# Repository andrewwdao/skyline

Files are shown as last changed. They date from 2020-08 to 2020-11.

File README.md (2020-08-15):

| Supported Targets | ESP32 |
| --- | ----- |

# SOURCE CODE FOR THE SKYLINE SYSTEM

This folder is the source code for the skyline system which will use MCPWM module to control brushed dc motor, with local webserver control, wifi-manager integrated and 04 button for direct interaction.
 
This code is tested with VNH3ASP30 motor driver.

(c) 2020 Minh-An Dao, MIS-CTU, Can Tho

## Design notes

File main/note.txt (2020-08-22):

https://docs.espressif.com/projects/esp-idf/en/release-v4.2/esp32/api-guides/build-system.html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

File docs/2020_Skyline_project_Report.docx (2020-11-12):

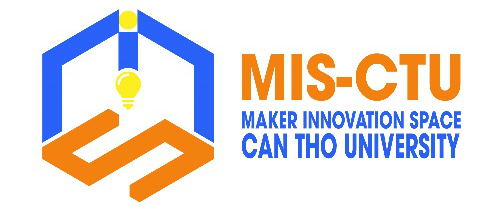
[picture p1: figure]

Người báo cáo:

- Nguyễn Khánh Trân Thiết kế cơ khí

- Nguyễn Minh Luân Thiết kế cơ khí

- Trần Thị Như Phụng Thiết kế mạch điện tử

- Đào Minh An Lập trình nhúng

Tổng kinh phí dự án:

Thời gian thực hiện:

BÁO CÁO DỰ ÁN

GIẾNG TRỜI ĐIỆN TỬ

08/2020

PHÊ DUYỆT DỰ ÁN

Tên dự án: Giếng trời điện tử

Thời gian thực hiện:

Tổng kinh phí:

Chủ đầu tư dự án:

Nơi áp dụng sản phẩm dự án:

Ngày dự án được phê duyệt thông qua và cho phép sử dụng:

Thành viên thực hiện dự án:

Họ và tên | Trách nhiệm | Ký tên
Nguyễn Khánh Trân | Thiết kế cơ khí
Nguyễn Minh Luân | Thiết kế cơ khí
Trần Thị Như Phụng | Thiết kế mạch điện tử
Đào Minh An | Lập trình nhúng
Nguyễn Hoàng Dũng | Chịu trách nhiệm dự án, kiểm duyệt và thông qua dự án

MỤC LỤC

MỤC LỤC HÌNH

# PHẦN 1: THUYẾT MINH DỰ ÁN

## 1.1 MỤC TIÊU DỰ ÁN

Xây dựng hệ thống điều khiển cửa sổ giếng trời thông qua webapp hoặc remote.

## 1.2 KẾT QUẢ MONG ĐỢI CỦA DỰ ÁN

Giếng trời có thể được điều khiển đóng/mở thông qua webapp hoặc remote từ xa.

## 1.3 KẾ HOẠCH THỰC HIỆN

01/09/2020 – 05/09/2020: Thiết kế cơ khí.

06/09/2020 – 07/09/2020: Gia công cơ khí.

01/09/2020 – 07/09/2020: Vẽ mạch điện, lập trình nhúng.

08/09/2020 – 10/09/2020: Thử nghiệm và tiến hành lắp đặt.

## 1.4 DỰ TOÁN KINH PHÍ

# PHẦN 2: THỰC HIỆN DỰ ÁN

## 2.1 THIẾT KẾ PHẦN CỨNG

### 2.1.1 THIẾT KẾ CƠ KHÍ

#### 2.1.1.1 Bản vẽ và mô tả bản vẽ lắp có kích thước

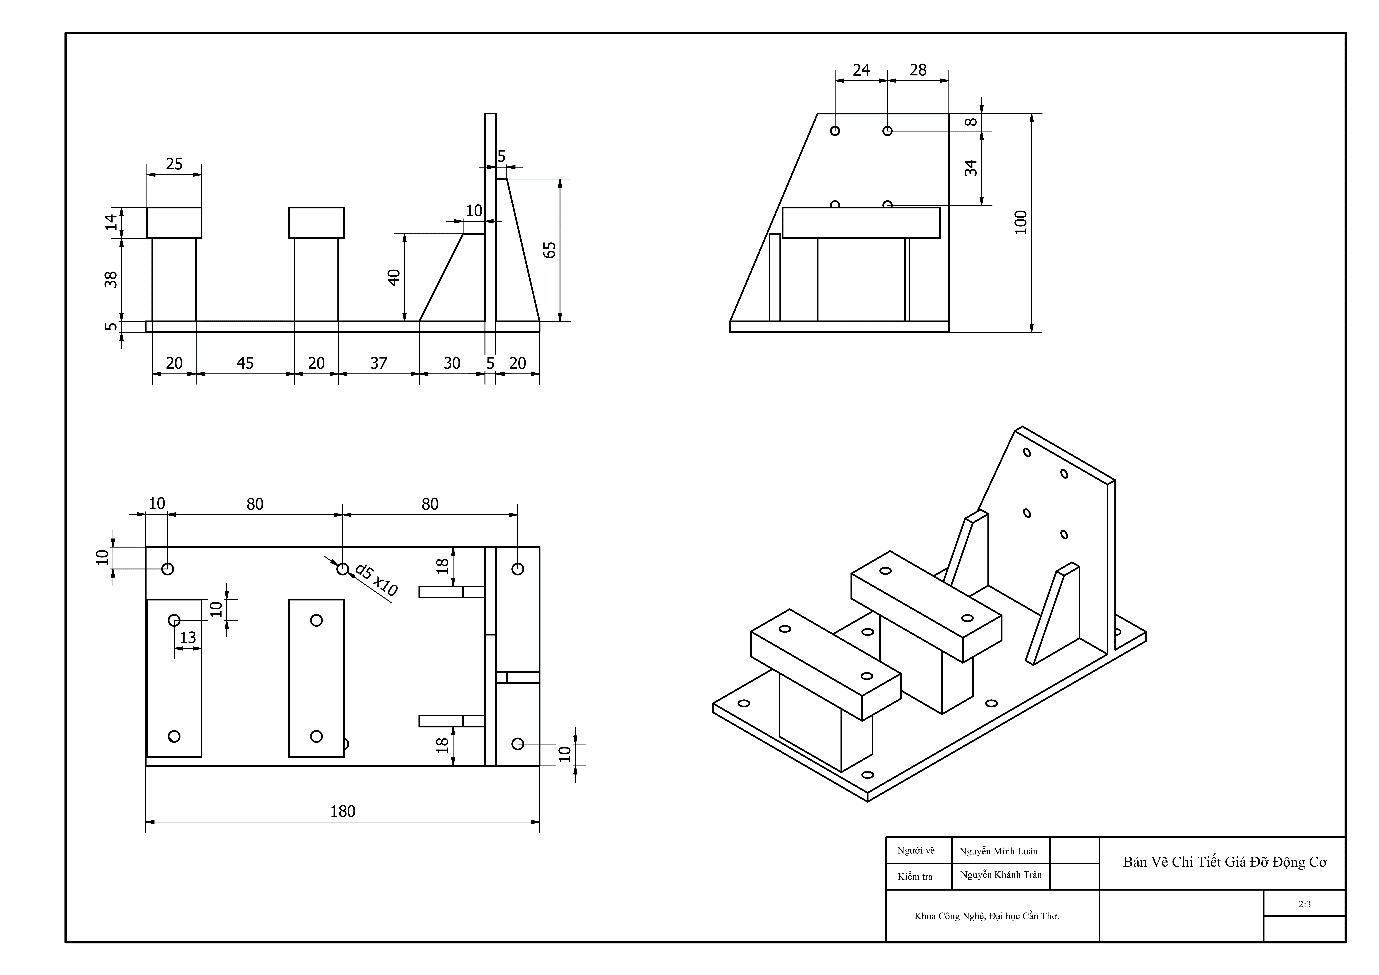
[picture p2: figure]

Hình 1. Bản vẽ mô tả bản vẽ chi tiết giá đỡ động cơ

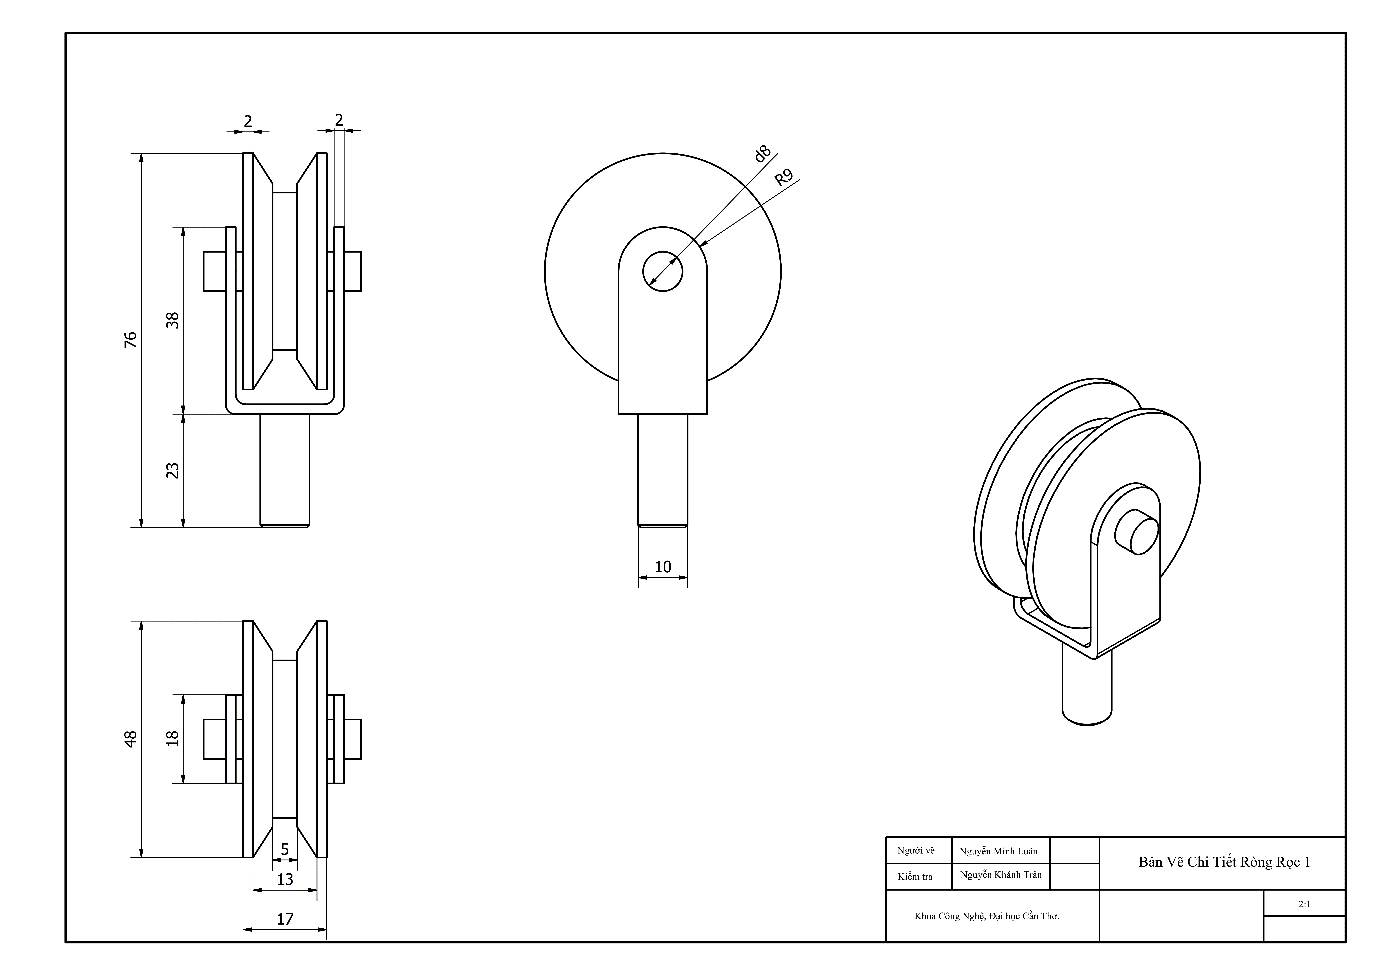
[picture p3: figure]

Hình 2. Bản vẽ chi tiết ròng rọc 1

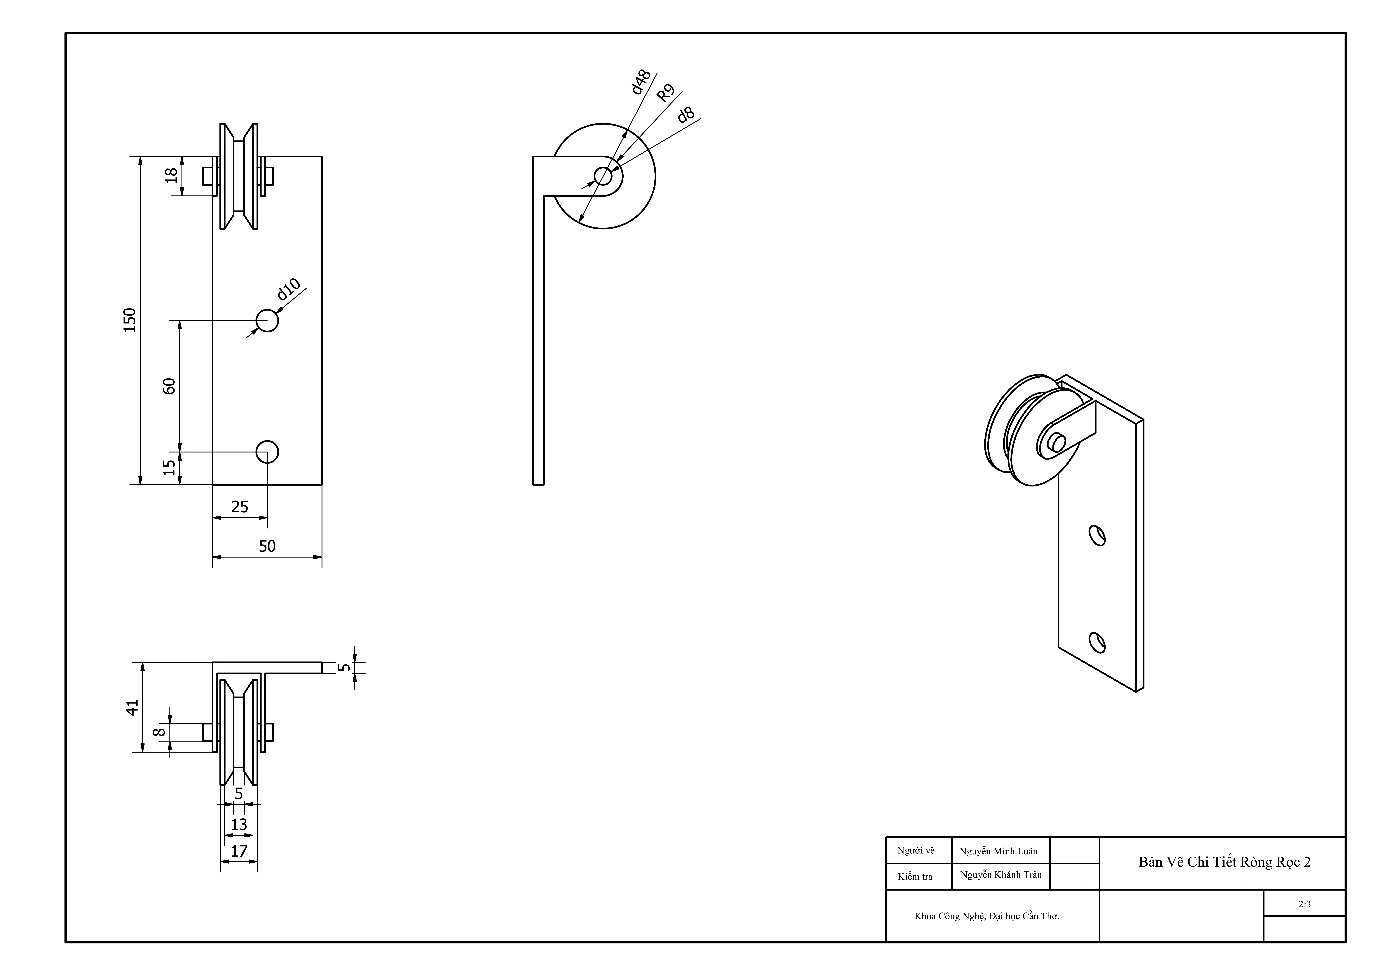
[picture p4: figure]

Hình 3. Bản vẽ chi tiết ròng rọc 2

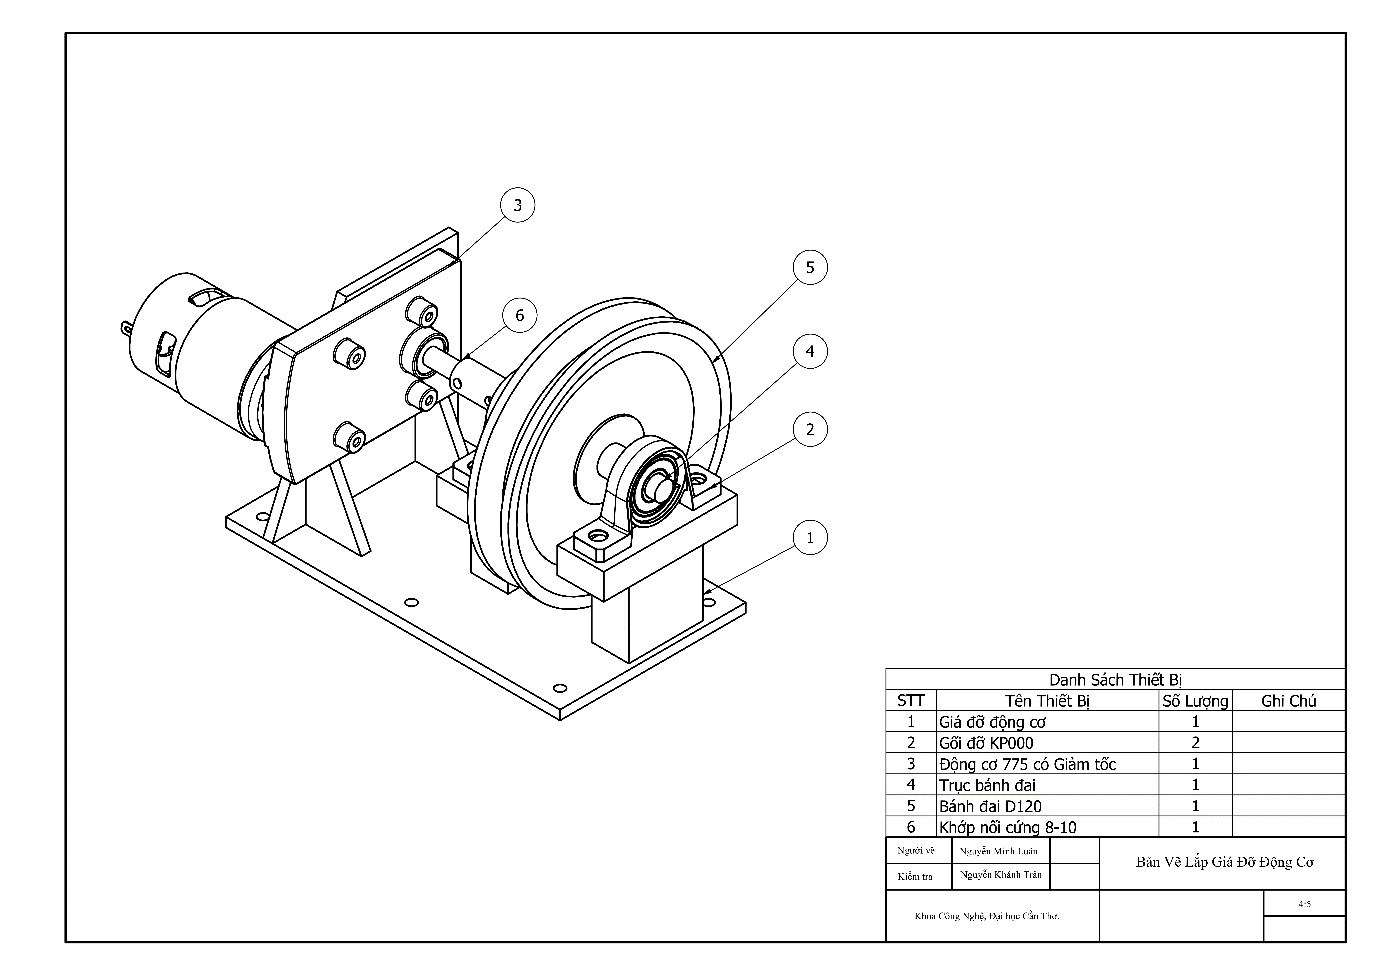
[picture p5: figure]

Hình 4. Bản vẽ lắp giá đỡ động cơ

#### 2.1.1.2 Bản vẽ và mô tả bản vẽ hoàn chỉnh

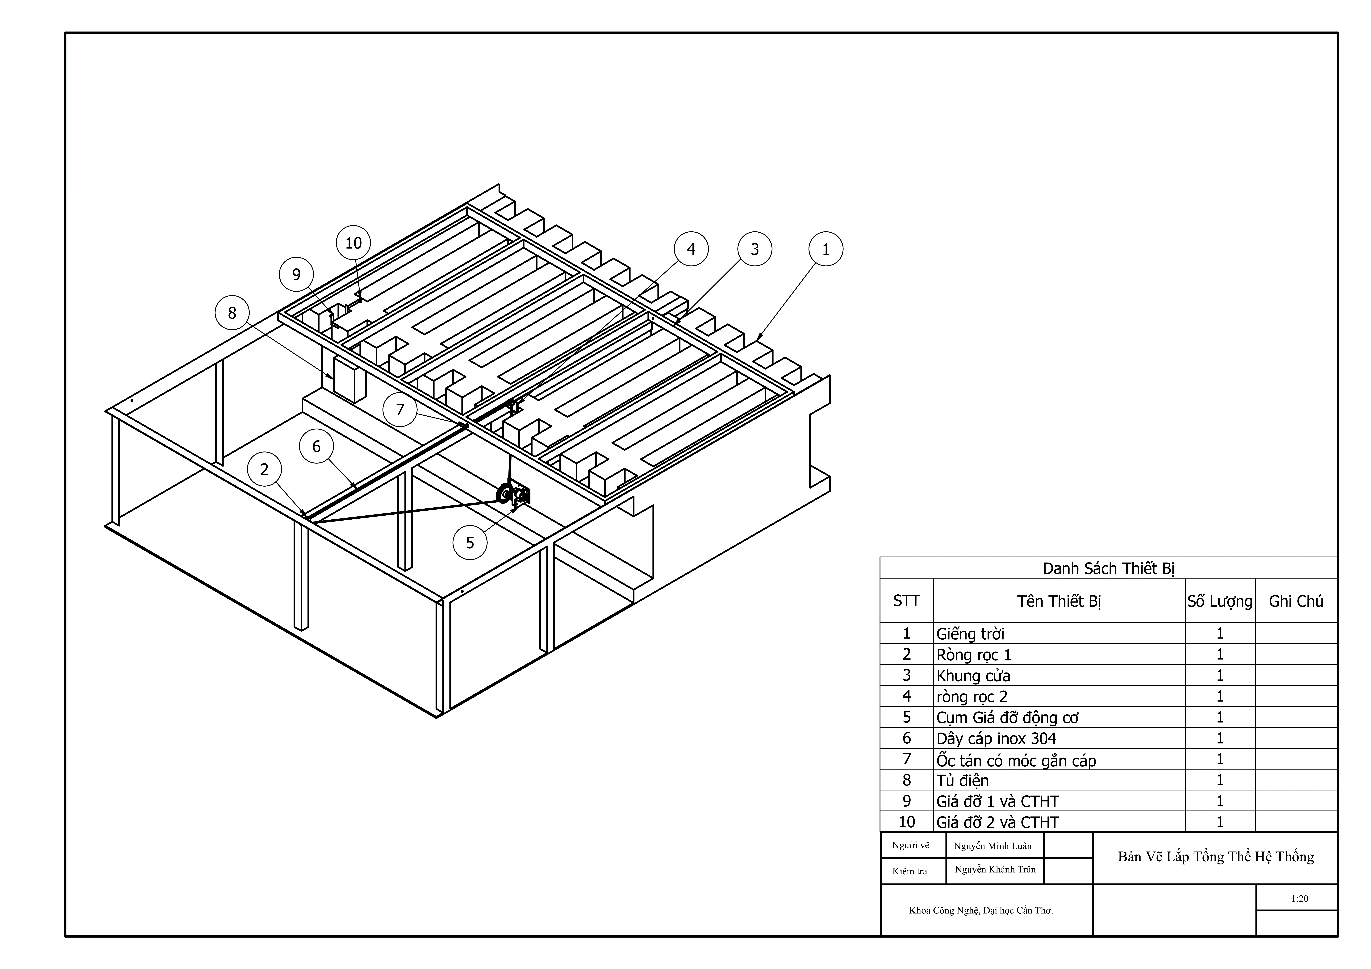
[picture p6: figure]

Hình 5. Bản vẽ lắp tổng thể hệ thống

### 2.1.2 THIẾT KẾ MẠCH ĐIỆN TỬ

#### 2.1.2.1 Sơ đồ khối của phần mạch điện tử và mô tả chi tiết chức năng các khối

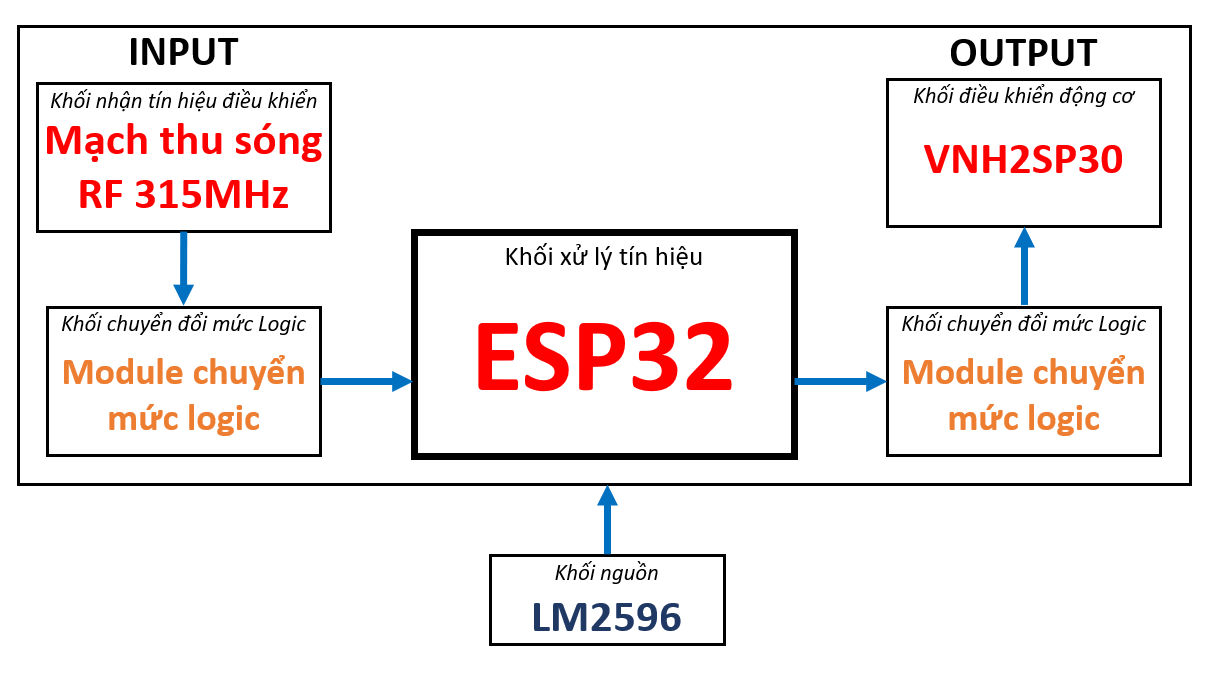
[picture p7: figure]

Hình 6. Sơ đồ khối của mạch điện tử

#### 2.1.2.2 Bản vẽ mạch nguyên lý

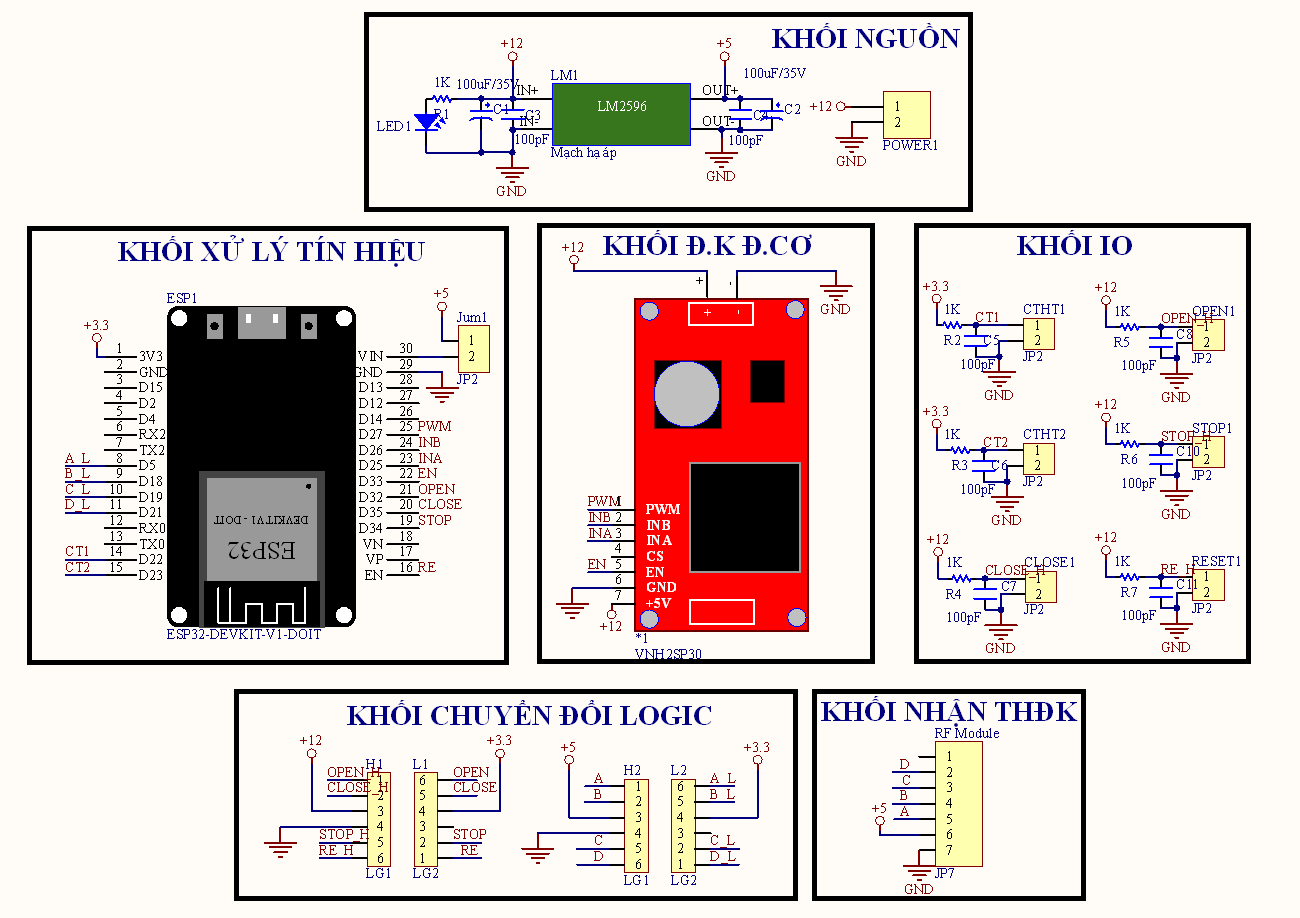
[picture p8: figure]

Hình 7. Bản vẽ mạch nguyên lý

#### 2.1.2.3 Bản vẽ mạch PCB

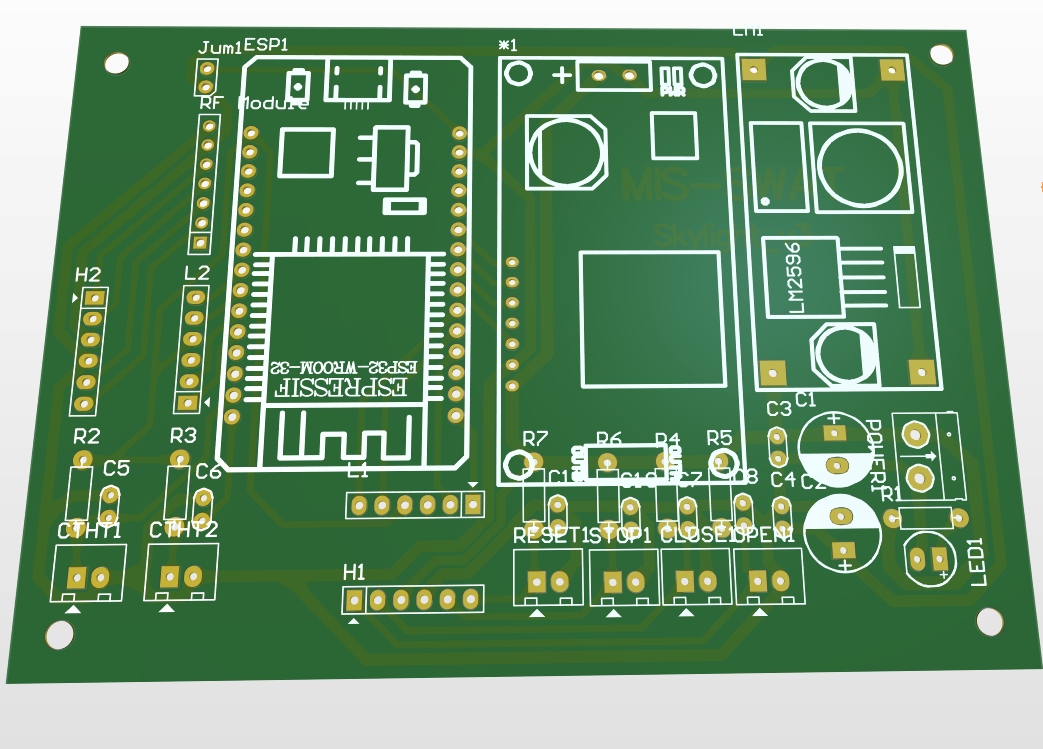
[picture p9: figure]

Hình 8. Bản vẽ mạch PCB

#### 2.1.2.4 Danh sách linh kiện, qui cách và trị số của từng linh kiện

Bảng 1. Danh sách linh kiện

STT | Khối | Tên linh kiện | SL
1 | Khối xử lý tín hiệu | ESP32 DEVKIT V1 | 1
2 | Khối điều khiển động cơ | Module VNH2SP30 | 1
3 | Khổi chuyển đổi mức logic | Module chuyển đổi mức logic 4 kênh | 2
4 | Khối nhận tín hiệu điều khiển | Module thu sóng RF 315MHz | 1
5 | Khối nguồn | Module hạ áp LM2596 | 1
| | Led nguồn | 1
| | Tụ lọc nguồn 100uF | 2
| | Tụ lọc nguồn 104 | 2
| | Header nguồn | 1
6 | Khối IO | Điện trở kéo lên 1K | 6
| | Tụ điện 104 | 6
| | Header 2 | 6
7 | Khác | Rào cái | 5
| | Rào đực | 5

#### 2.1.2.5 Bản hướng dẫn lắp đặt mạch điện chi tiết

- Bước 1: Gia công mạch PCB
- Bước 2: Đo thông mạch cách đường dây cẩn thận trước khi bắt đầu lắp đặt linh kiện
- Bước 3: Gắn các linh kiện tương thích giữa mạch PCB và file nguyên lý. (Gắn các linh kiện theo thứ tự có chiều cao tang dần)
- Bước 4: Hàn các linh kiện vào các vị trí đã được xác định tại bước 3
- Bước 5: Đo thông mạch giữa các đường dây trước khi gắn các module quan trọng
- Bước 6: Gắn đầy đủ các module lên board PCB và test từng chức năng của hệ thống.

## 2.2 THIẾT KẾ PHẦN MỀM

### 2.2.1 PHẦN MỀM LÕI (FIRMWARE)

Toàn bộ source code hệ thống có thể được tìm thấy tại:

https://github.com/minhan74/skyline

Bộ điều khiển trung tâm của hệ thống là vi điều khiển ESP32 (module ESP32 DevKit V1).

Hệ thống được lập trình trên Visual Studio Code, thông qua trình biên dịch ESP-IDF v4.2 (commit dddcc2ede).

### 2.2.2 PHẦN MỀM ỨNG DỤNG (CHẠY TRÊN MÁY TÍNH/ĐIỆN THOẠI)

Hiện tại hệ thống có thể kết nối vào wifi Nguyen Khuong 4 (wifi của chủ nhà).

Thông tin Wifi, tốc độ động cơ có thể được thay đổi bằng cách chạy lệnh:

idf.py menuconfig

chọn mục Skyline Window Configuration.

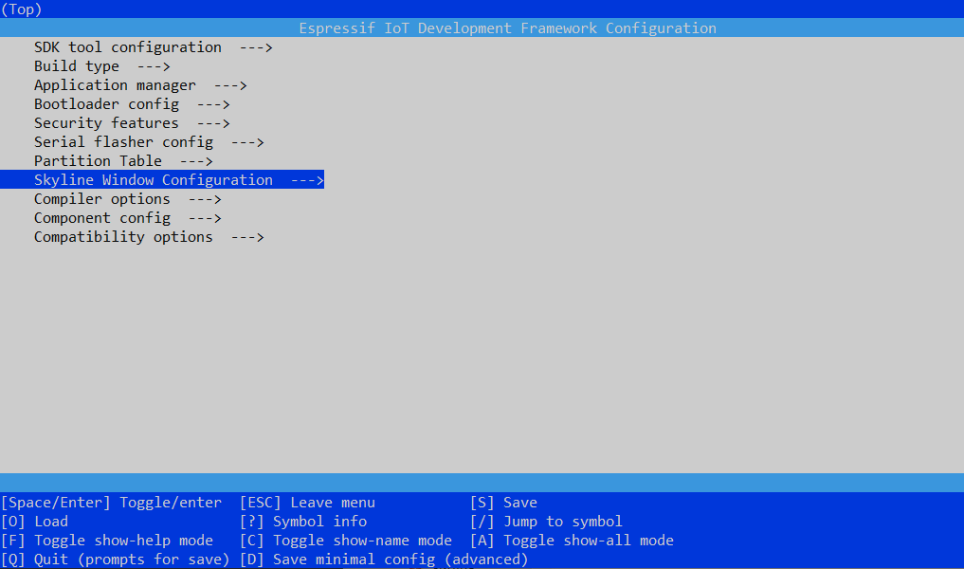
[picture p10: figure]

Sau khi kết nối wifi thành công, webapp có thể được truy cập thông qua:

http://192.168.1.174:7497/ctl

## 2.3 MỘT SỐ YÊU CẦU CỦA SẢN PHẨM

Hộp điều khiển của hệ thống có thể chống nước nhẹ, tuy nhiên vẫn nên lắp đặt tại vị trí hạn chế tối đa tiếp xúc với điều kiện ẩm ướt.

# PHẦN 3: KẾT QUẢ DỰ ÁN

## 3.1 THỬ NGHIỆM SẢN PHẨM

- Sản phẩm hoạt động tốt trong thời gian demo.

- Sản phẩm hoạt động tốt sau 1 tháng sử dụng. Có nâng cấp hệ thống nguồn dự phòng UPS và hệ thống LED báo hoạt động.

## 3.2 SẢN PHẨM HOÀN CHỈNH

### 3.2.1 Phần cứng

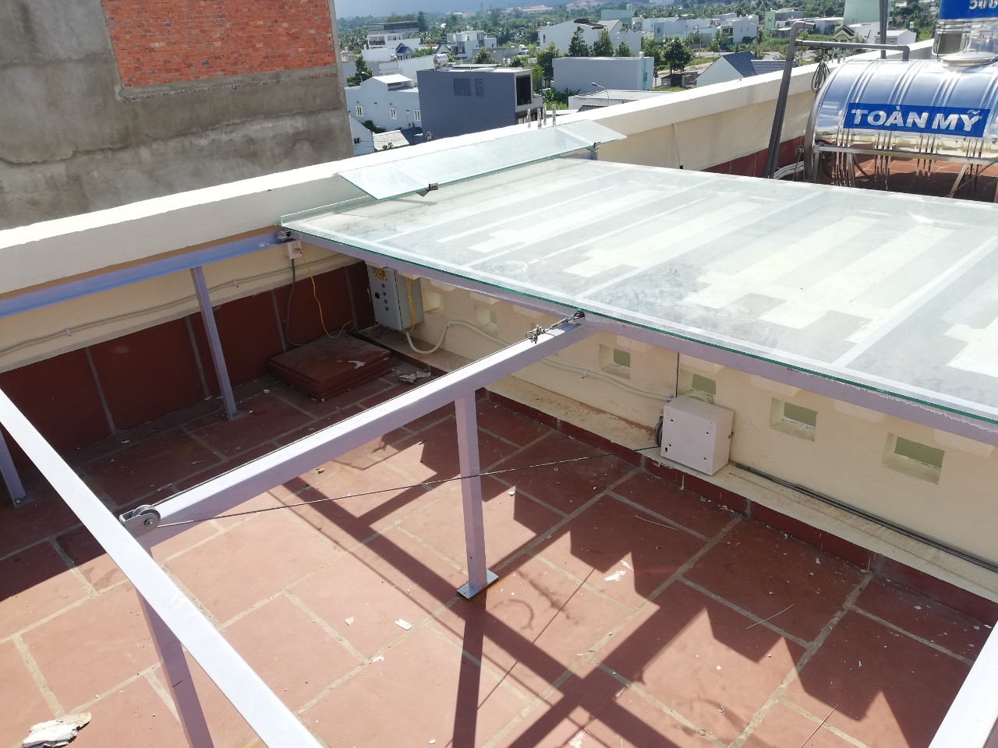
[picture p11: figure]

Hình 9. Hình ảnh thực tế 1

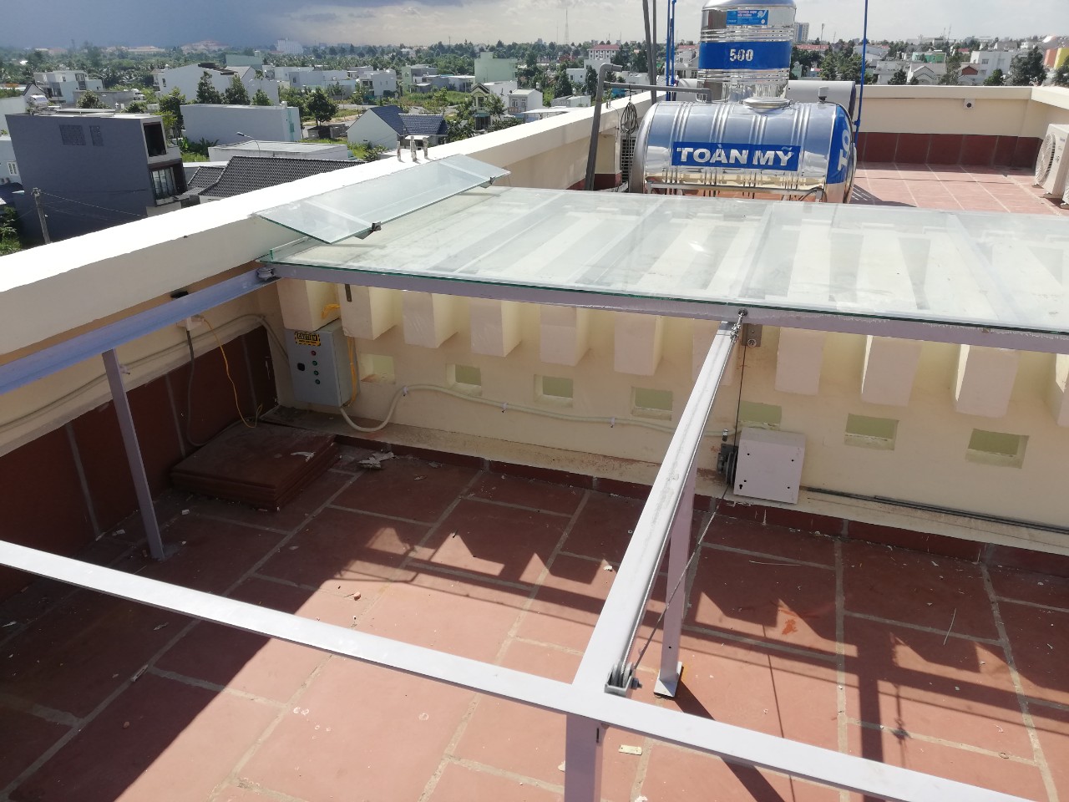
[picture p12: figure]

Hình 10. Hình ảnh thực tế 2

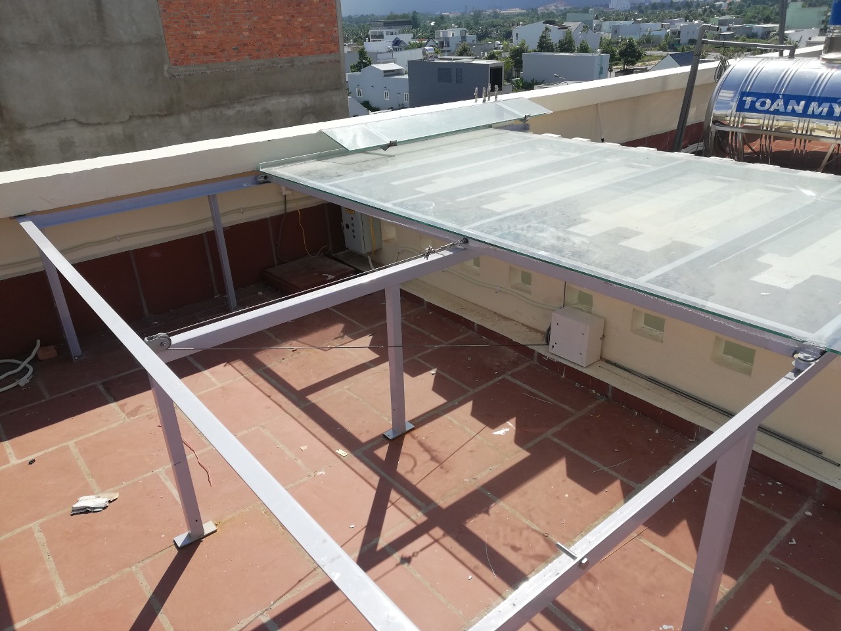
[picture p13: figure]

Hình 11. Hình ảnh thực tế 3

### 3.2.2 Phần mềm

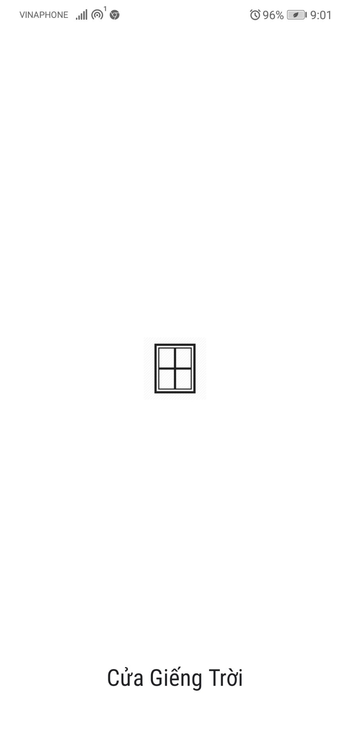
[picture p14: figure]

Hình 12. Shortcut trên điện thoại và máy tính

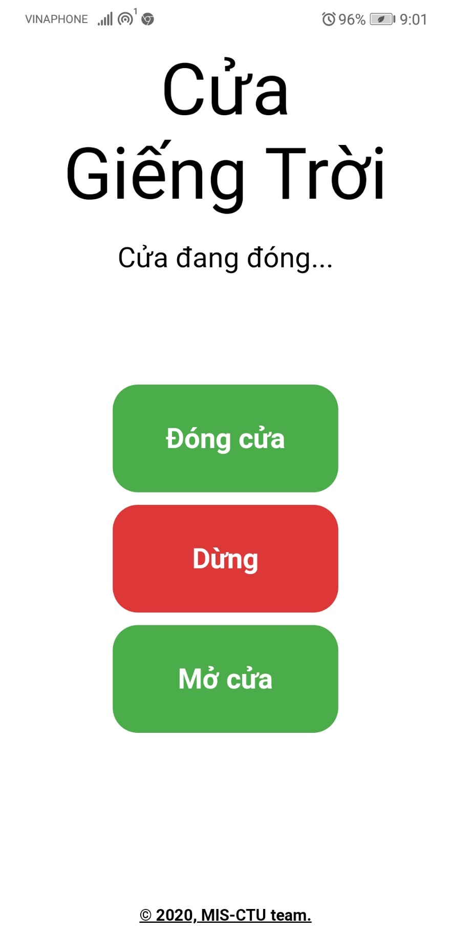
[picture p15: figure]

Hình 13. Giao diện web điều khiển khi hoạt động

## 3.3 ĐÓNG GÓI SẢN PHẨM

Các file liên quan được đóng gói kèm theo bài báo cáo.

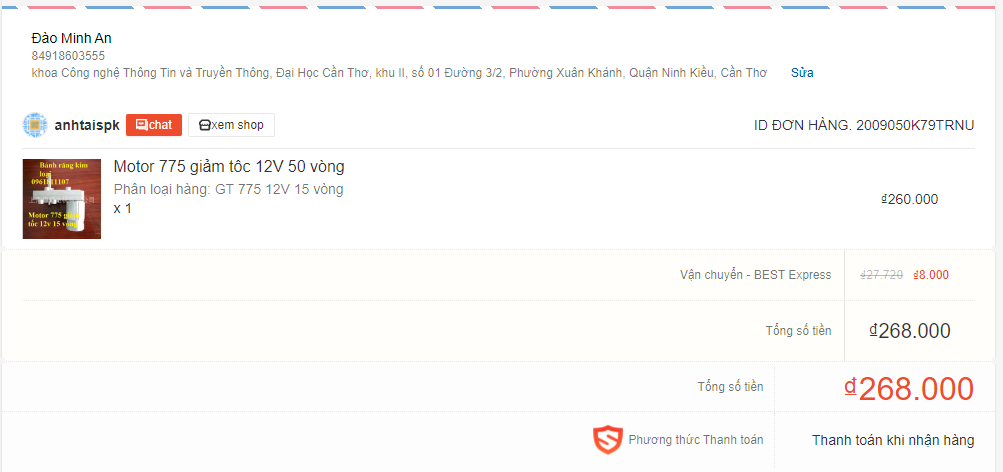
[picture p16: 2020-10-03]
extra_bills/05092020_shopee.PNG

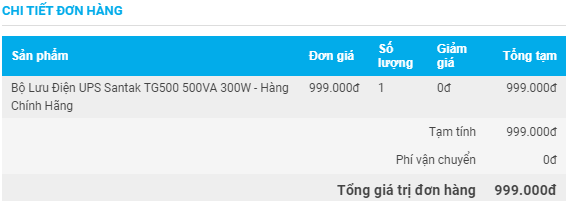
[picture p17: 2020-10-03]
extra_bills/05092020_tiki.PNG

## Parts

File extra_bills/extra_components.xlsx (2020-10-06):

STT | Tên | Giá | LINK | Ghi chú
1 | UPS Santak TG500 | VND 999000.00 | https://tiki.vn/bo-luu-dien-ups-santak-tg500-500va-300w-ha-ng-chi-nh-ha-ng-p10194812.html | giữ kết nối được khoảng 10-30p sau khi mất điện
2 | động cơ giảm tốc 775 15 vòng | VND 268000.00 | https://shopee.vn/Motor-775-gi%E1%BA%A3m-t%E1%BB%91c-12V-50-v%C3%B2ng-i.21590269.2718118314
3
Tổng |  | VND 1267000.00
Thầy ứng |  | VND 1000000.00

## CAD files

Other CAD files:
Mechanical/Bản vẽ 2D/Bản vẽ lắp - Giá đỡ động cơ .dwg
Mechanical/Bản vẽ 2D/Bản chi tiết - Giá đỡ động cơ.dwg
Mechanical/Bản vẽ 2D/Bản chi tiết - Ròng rọc 2 .dwg
Mechanical/Bản vẽ 2D/Bản vẽ lắp - Tổng thể.dwg
Mechanical/Bản vẽ 2D/Bản chi tiết - Ròng rọc 1.dwg
Mechanical/Bản vẽ 2D/OldVersions/Bản vẽ lắp - Tổng thể.0012.dwg
Mechanical/Bản vẽ 2D/OldVersions/Bản vẽ lắp - Giá đỡ động cơ .0010.dwg
Mechanical/Bản vẽ 2D/OldVersions/Bản chi tiết - Ròng rọc 2 .0013.dwg
Mechanical/Bản vẽ 2D/OldVersions/Bản chi tiết - Giá đỡ động cơ.0013.dwg
Mechanical/Bản vẽ 2D/OldVersions/Bản chi tiết - Ròng rọc 1.0014.dwg
Mechanical/Bản vẽ 3D/Bản vẽ mô tả 3D - Giá đỡ động cơ.iam
Mechanical/Bản vẽ 3D/Bản vẽ mô tả 3D.iam
Mechanical/Bản vẽ 3D/Giá đỡ động cơ + trục/Giá đỡ động cơ.ipt
Mechanical/Bản vẽ 3D/Giá đỡ động cơ + trục/OldVersions/Giá đỡ động cơ.0023.ipt
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

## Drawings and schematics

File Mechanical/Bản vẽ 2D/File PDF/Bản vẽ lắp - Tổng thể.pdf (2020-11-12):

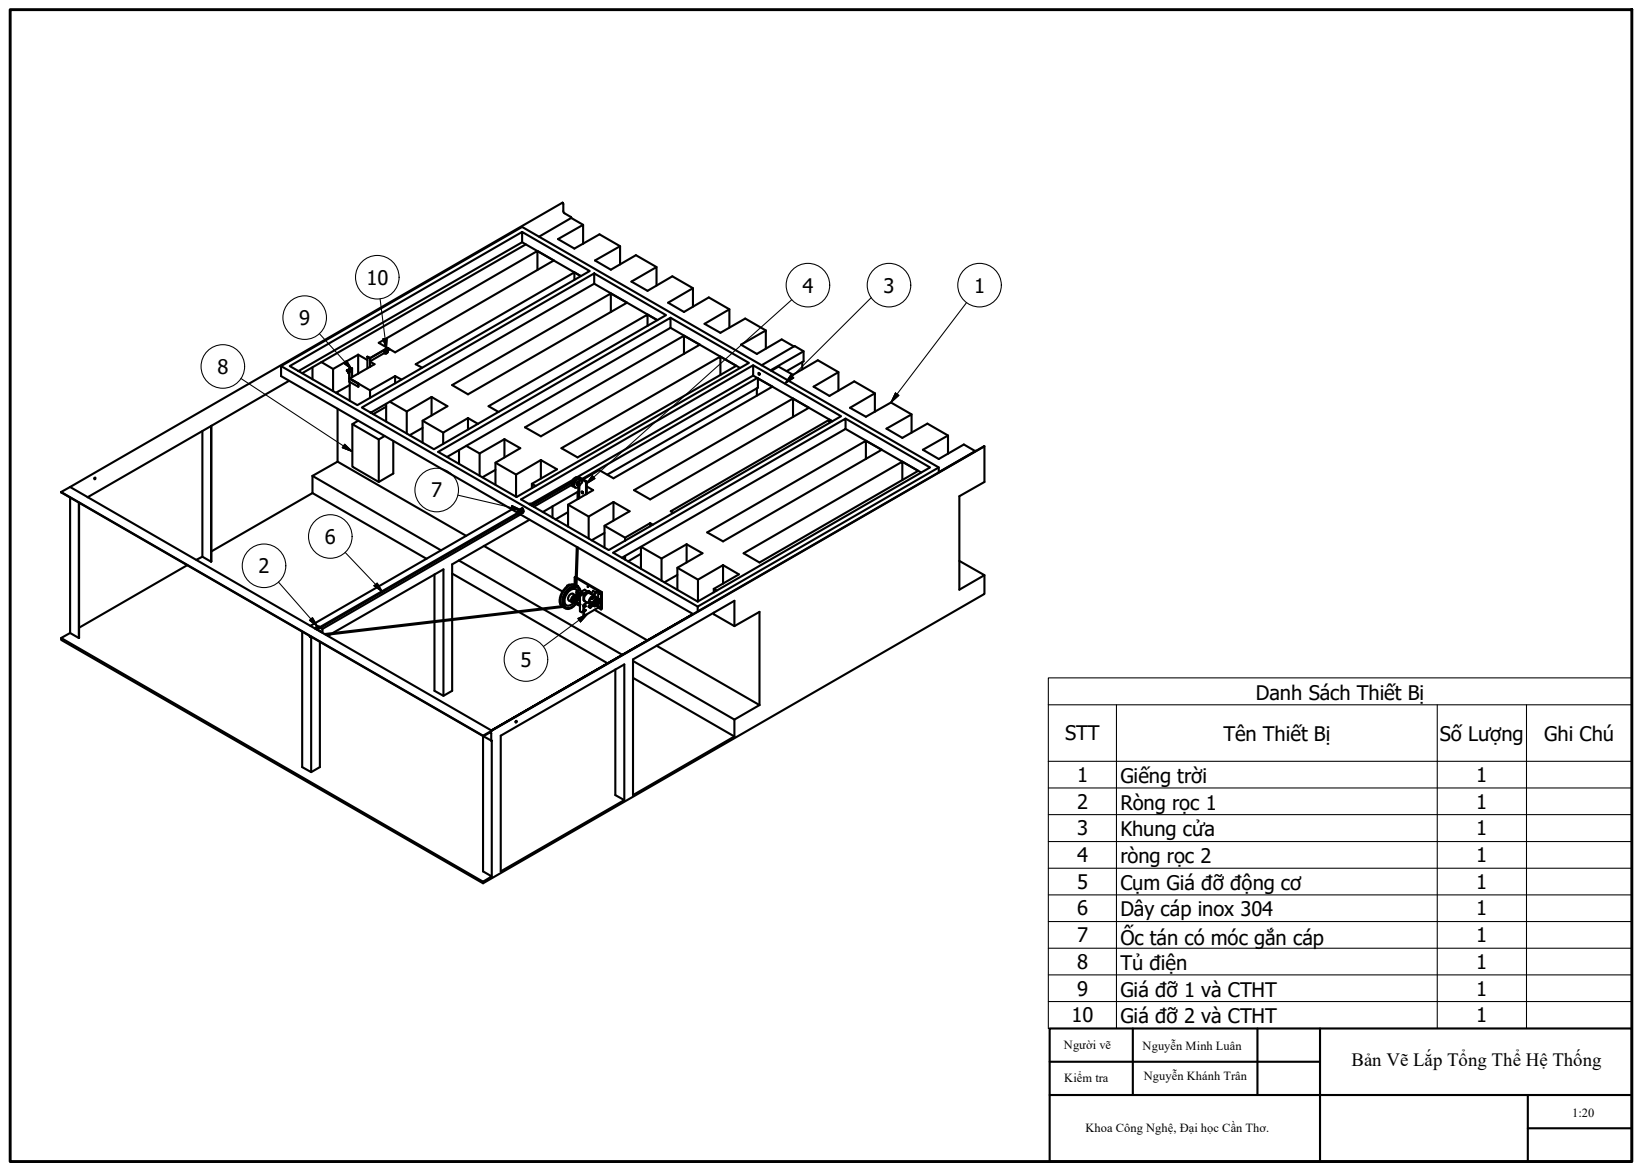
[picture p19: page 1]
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

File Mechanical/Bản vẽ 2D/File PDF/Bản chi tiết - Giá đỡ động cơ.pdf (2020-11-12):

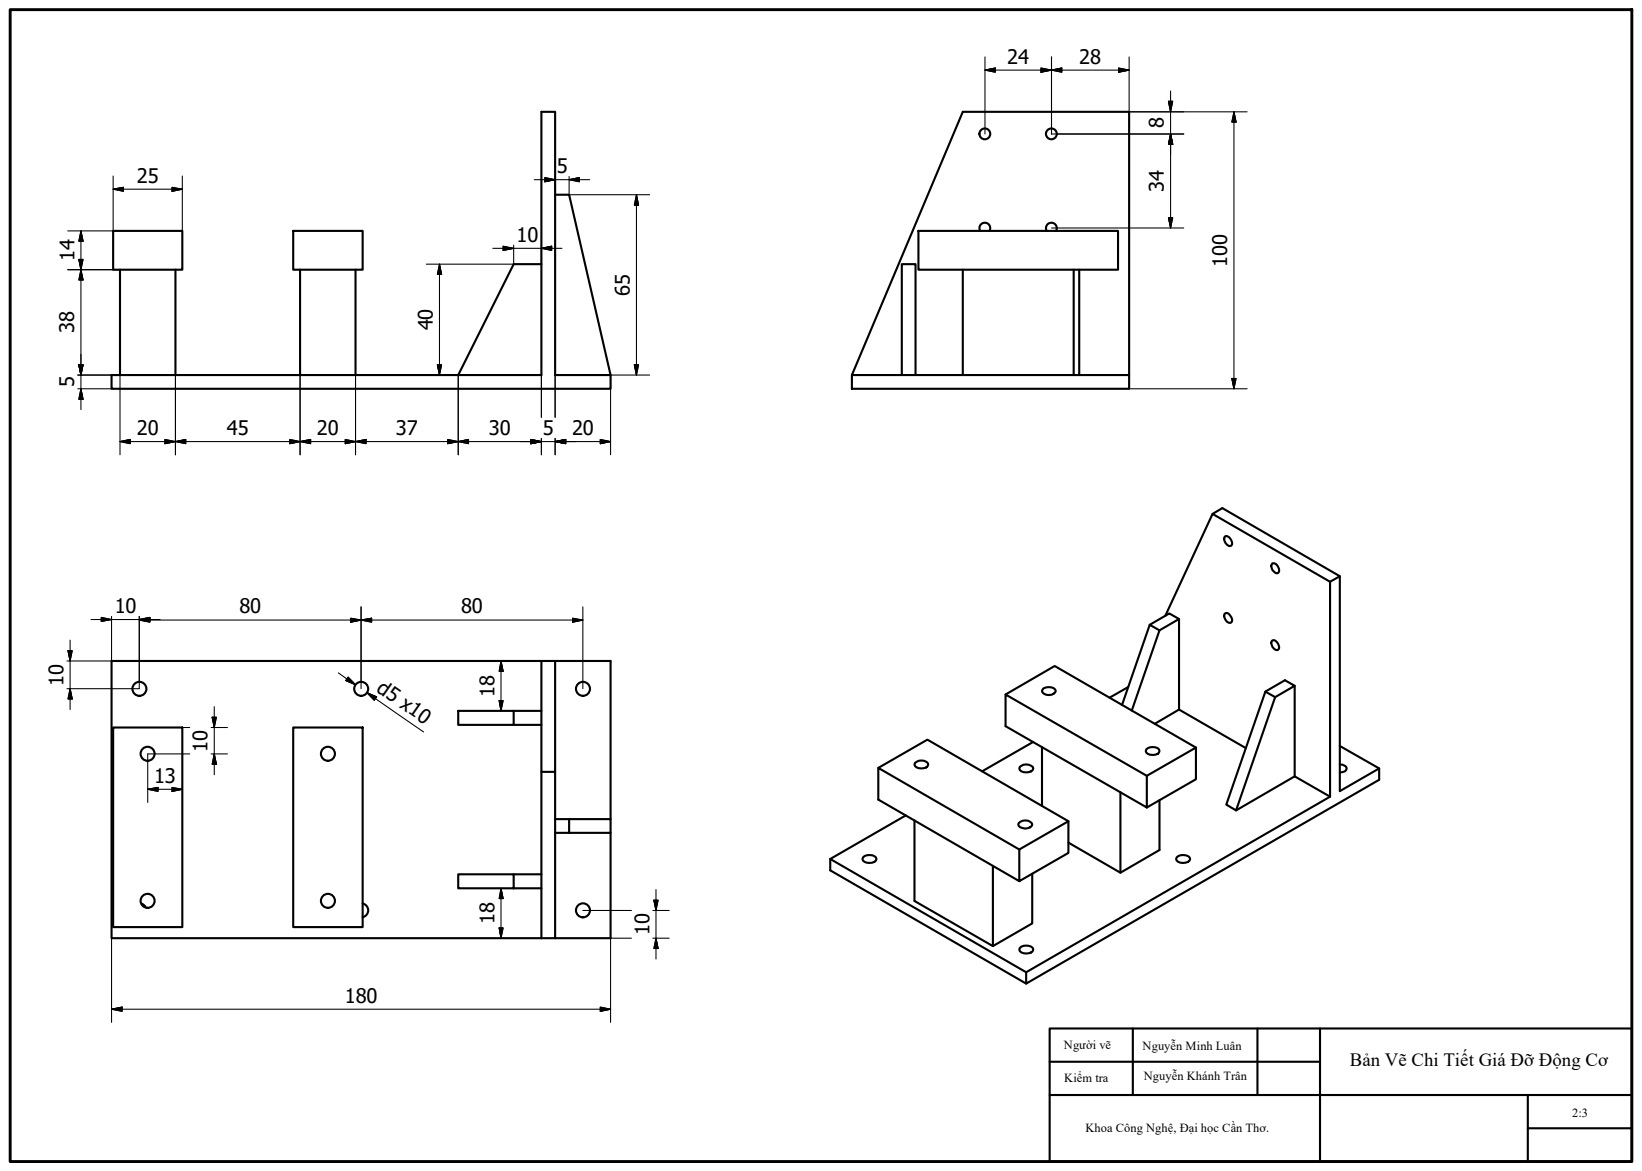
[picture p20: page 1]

Ngi v | Nguyn Minh Lukn | | Bn V Chi Tit Gii  ng C

Kim tra | Nguyn Khinh Trkn

Khoa C{ng Ngh, i hc Cn Th. | | 2:3

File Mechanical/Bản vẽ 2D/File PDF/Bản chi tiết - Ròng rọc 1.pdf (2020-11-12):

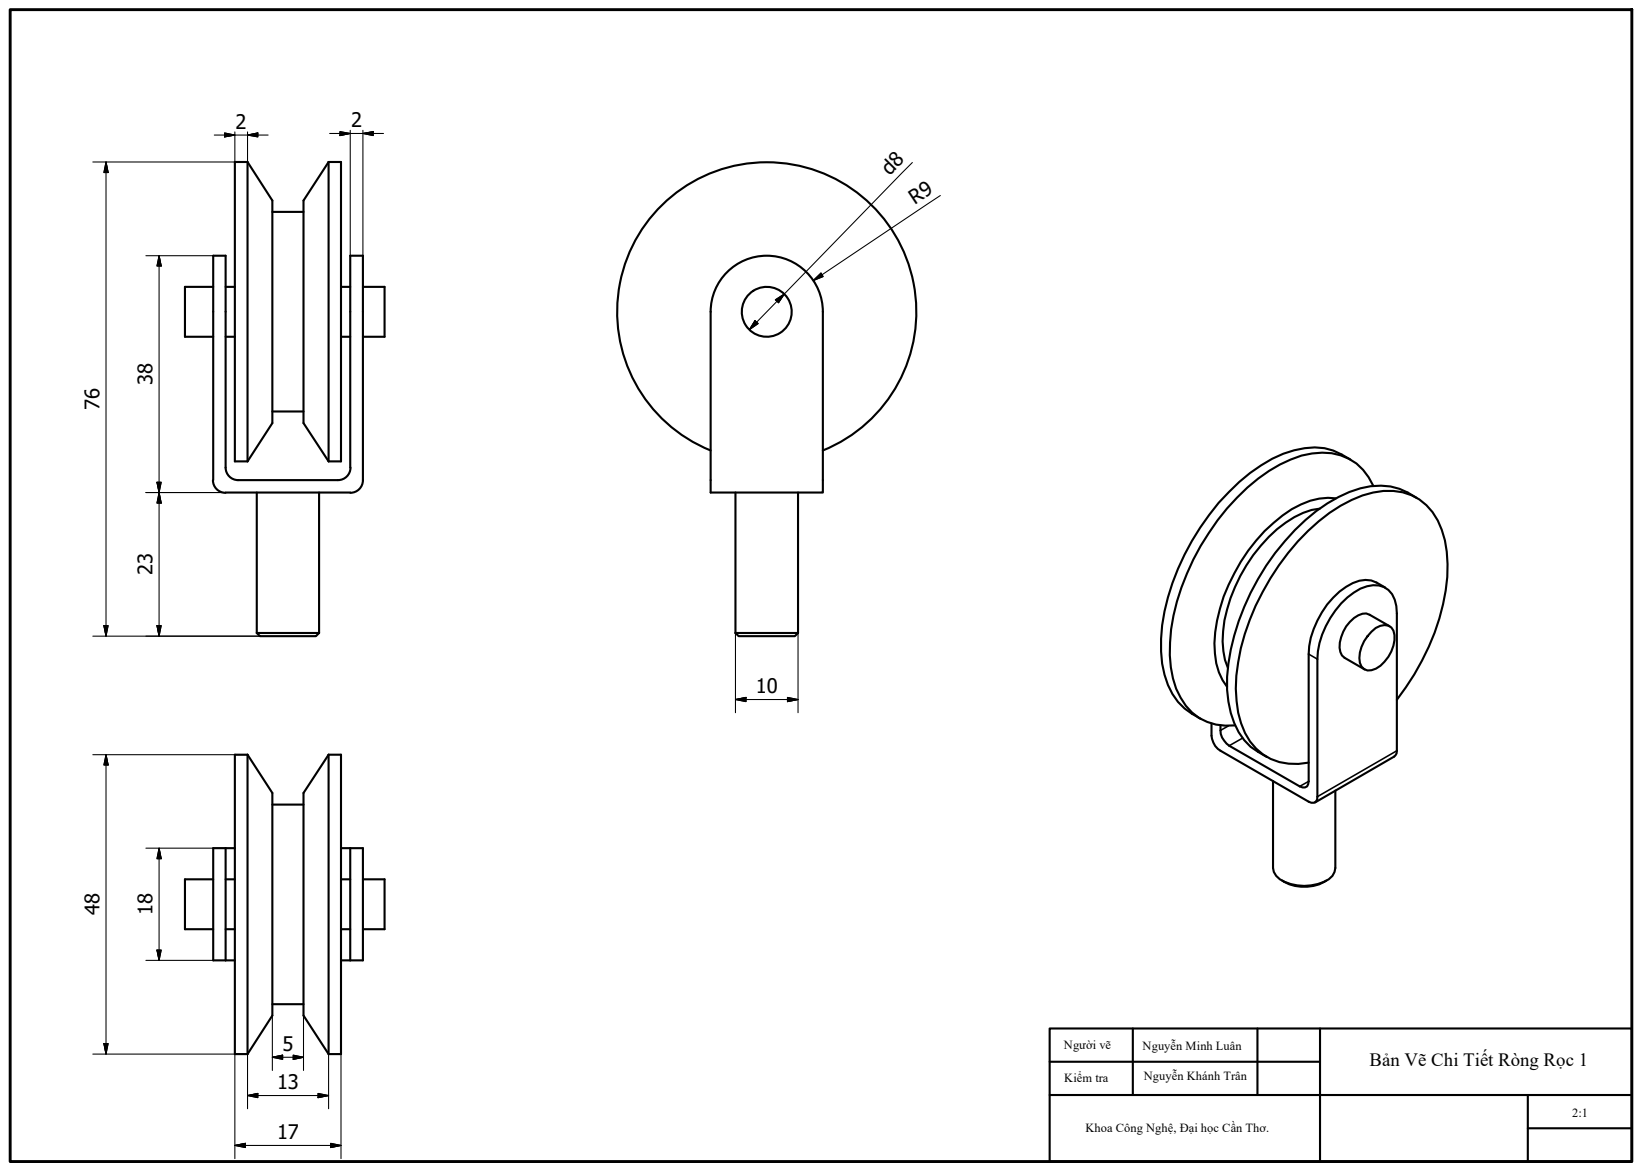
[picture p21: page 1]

Ngi v | Nguyn Minh Lukn | Bn V Chi Tit Rzng Rc 1

Kim tra | Nguyn Khinh Trkn

Khoa C{ng Ngh, i hc Cn Th.

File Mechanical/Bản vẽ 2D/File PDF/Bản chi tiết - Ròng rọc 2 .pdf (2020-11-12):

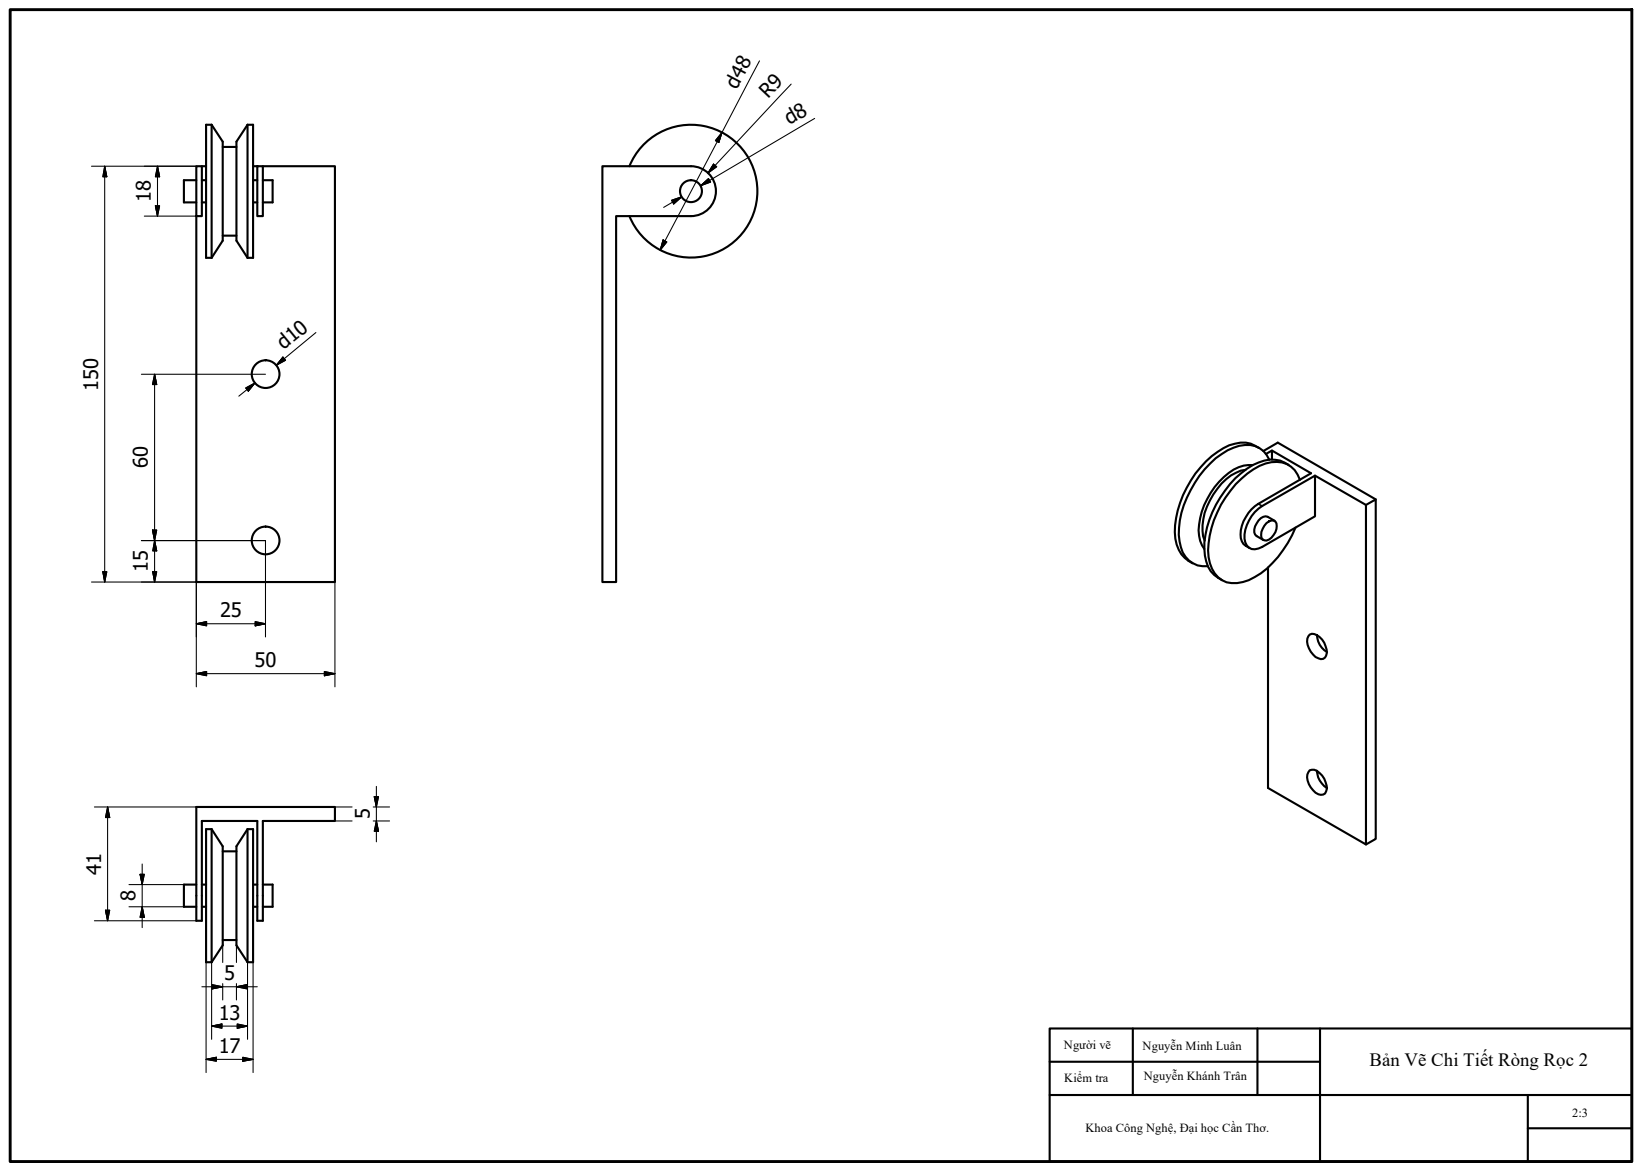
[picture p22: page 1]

Bn V Chi Tit Rzng Rc 2

Kim tra | Nguyn Khinh Trkn

Khoa C{ng Ngh, i hc Cn Th. | | 2:3

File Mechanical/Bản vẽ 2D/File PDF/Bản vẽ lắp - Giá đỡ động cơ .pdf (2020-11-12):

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

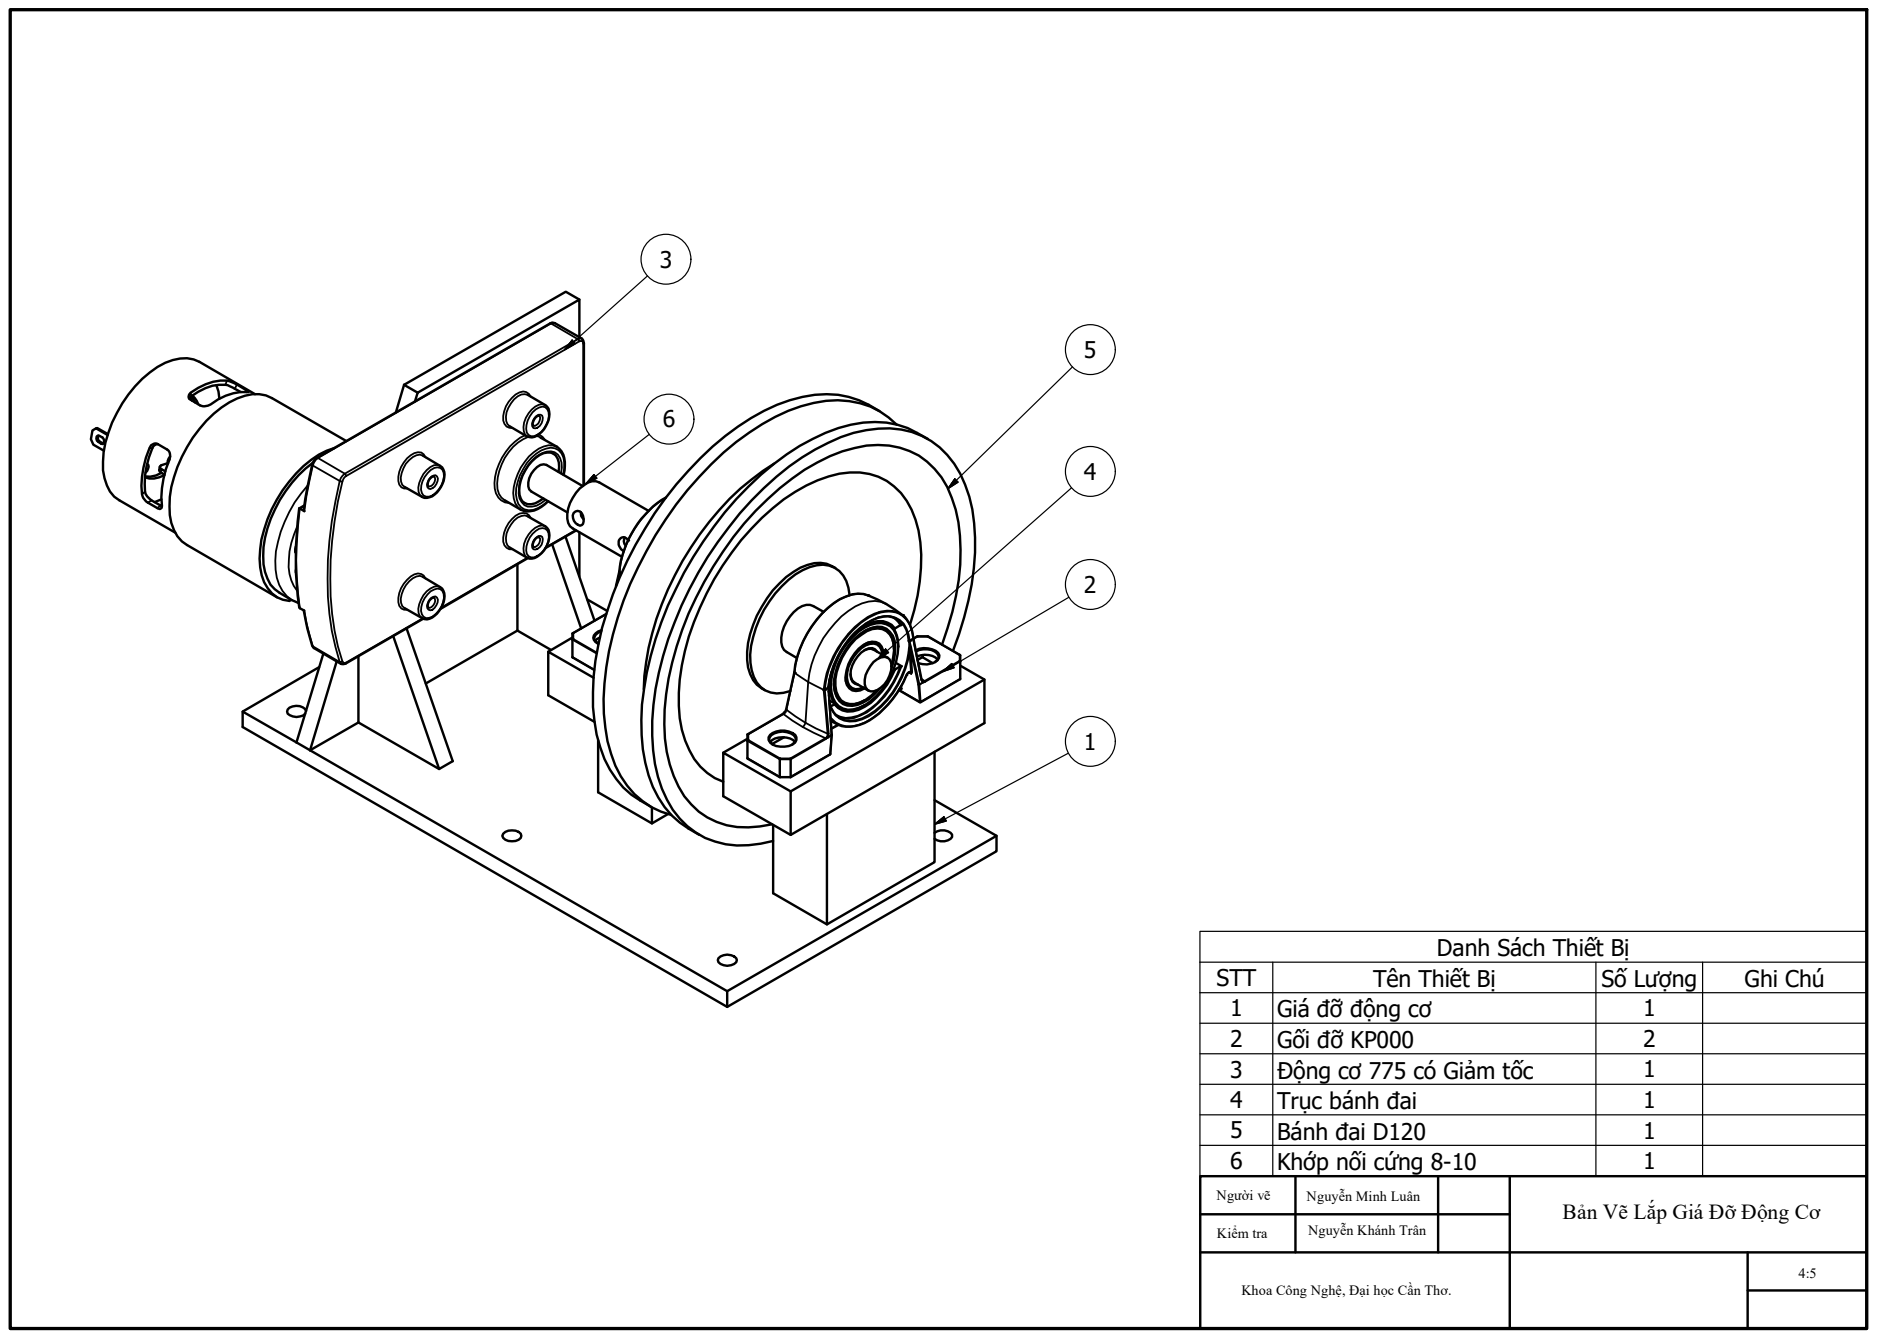
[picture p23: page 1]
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

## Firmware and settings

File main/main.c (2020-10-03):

/*------------------------------------------------------------*-
  main - source file
  (c) Minh-An Dao - Anh Khoi Tran - Nhu-Phung Tran-Thi 2020
  version 1.00 - 20/08/2020
---------------------------------------------------------------
 * 
 --------------------------------------------------------------*/
#include "config.h"
#include "motor.h"
#include "webserver.h"

// ------ Public variables ------------------------------------
/** @brief status of the gate, which will involve control the motor */
char GATE_STATE = STOPPED;
/** @brief flag for stopping the motor */
bool STOP_FLAG = false;
/** @brief tag used for ESP serial console messages */
static const char TAG[] = "MAIN";

//--------------------------------------------------------------
// FUNCTION DEFINITIONS
//--------------------------------------------------------------
/**
 * @brief auto disconnect_handler for stopping webserver in wifi service
 */
static void disconnect_handler(void* arg, esp_event_base_t event_base, 
                               int32_t event_id, void* event_data)
{
    httpd_handle_t* server = (httpd_handle_t*) arg;
    if (*server) {
        ESP_LOGI(TAG, "Stopping webserver...");
        stop_webserver(*server);
        *server = NULL;
    }
}
/**
 * @brief auto connect_handler for creating webserver in wifi service
 */
static void connect_handler(void* arg, esp_event_base_t event_base, 
                            int32_t event_id, void* event_data)
{
    httpd_handle_t* server = (httpd_handle_t*) arg;
    if (*server == NULL) {
        ESP_LOGI(TAG, "Starting webserver...");
        *server = start_webserver();
    }
}

/**
 * @brief RTOS task that periodically prints the heap memory available.
 * @note Pure debug information, should not be ever started on production code! This is an example on how you can integrate your code with wifi-manager
 */
// void monitoring_task(void *arg)
// {
// 	for(;;){
// 		ESP_LOGI(TAG, "free heap: %d\n",esp_get_free_heap_size());
// 		vTaskDelay(pdMS_TO_TICKS(10000));
// 	}
// }

/**
 * @brief main app
 */
void app_main(void)
{
    // --------Initialize NVS - must have on main task -------
    esp_err_t ret = nvs_flash_init();
    if (ret == ESP_ERR_NVS_NO_FREE_PAGES || ret == ESP_ERR_NVS_NEW_VERSION_FOUND) {
        ESP_ERROR_CHECK(nvs_flash_erase());
        ret = nvs_flash_init();
    }
    ESP_ERROR_CHECK(ret);
    
    //-------------- Motor task ------------------
    xTaskCreate(
        &motor_task,    /* Task Function */
        "motor_task",   /* Name of Task */
        4096,          /* Stack size of Task */
        NULL,           /* Parameter of the task */
        3,              /* Priority of the task, vary from 0 to N, bigger means higher piority, need to be 0 to be lower than the watchdog*/
        NULL);          /* Task handle to keep track of created task */

    //------------ Webserver task -----------------
    //wifi and webserver initialization and configuration
    wifiSTA_init();

    static httpd_handle_t server = NULL;
    ESP_ERROR_CHECK(esp_event_handler_register(IP_EVENT,
                                               IP_EVENT_STA_GOT_IP,
                                               &connect_handler, &server));
    ESP_ERROR_CHECK(esp_event_handler_register(WIFI_EVENT,
                                               WIFI_EVENT_STA_DISCONNECTED,
                                               &disconnect_handler, &server));

    server = start_webserver();

    //------------ monitoring task -----------------
    //A task on core 2 that monitors free heap memory - should be removed on production
    // xTaskCreatePinnedToCore(
    //     &monitoring_task,    /* Task Function */
    //     "monitoring_task",   /* Name of Task */
    //     2048,                /* Stack size of Task */
    //     NULL,                /* Parameter of the task */
    //     1,                   /* Priority of the task, vary from 0 to N, bigger means higher piority, need to be 0 to be lower than the watchdog*/
    //     NULL,                /* Task handle to keep track of created task */
    //     1);                  /* CoreID */

}

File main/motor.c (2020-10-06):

/*------------------------------------------------------------*-
  Brushed DC motor controller - source file
  (c) Minh-An Dao - Nhu-Phung Tran-Thi 2020
  version 1.10 - 20/08/2020
---------------------------------------------------------------
 * Use MCPWM module to control brushed dc motor.
 * 
 *  ** CAUTION:
 *  This core is responsible for RF radio, Wifi stack and protocols (watchdog,...) 
 *  Therefore, you have to be EXTREMELY CAREFUL when create task for this core,
 *  in order to not intefere these default functions (watchdog has the piority of 1 among 0 to N, higher number means higer piority)
 *
 --------------------------------------------------------------*/
#ifndef __MOTOR_C
#define __MOTOR_C
#include "motor.h"

#include "driver/mcpwm.h"
#include "soc/mcpwm_periph.h"

#include "freertos/queue.h"
#include "driver/gpio.h"

// ------ Private constants -----------------------------------
// --- pinout define ---
#define PWM_PIN 27 //Set GPIO as PWM0A
#define INA_PIN 25
#define INB_PIN 26
#define EN_PIN  33
#define MOTOR_PIN_SEL  ((1ULL<<EN_PIN)|(1ULL<<INA_PIN)|(1ULL<<INB_PIN))
  
// isr pins
#define OPEN_LIMIT_PIN  22
#define CLOSE_LIMIT_PIN 23
#define OPEN_DOOR_PIN 32
#define CLOSE_DOOR_PIN 35
#define STOP_DOOR_PIN 34
#define ISR_PIN_SEL  ((1ULL<<OPEN_LIMIT_PIN)|(1ULL<<CLOSE_LIMIT_PIN)|(1ULL<<OPEN_DOOR_PIN)|(1ULL<<CLOSE_DOOR_PIN)|(1ULL<<STOP_DOOR_PIN))
#define OPEN_RF_PIN 5
#define CLOSE_RF_PIN 18
#define STOP_RF_PIN 19
#define RF_PIN_SEL  ((1UL<<OPEN_RF_PIN)|(1ULL<<CLOSE_RF_PIN)|(1ULL<<STOP_RF_PIN))
// --- parameters define ---
// setting PWM properties
#define FREQ    10000
#define MAX_SPEED CONFIG_MAX_SPEED
#define MIN_SPEED CONFIG_MIN_SPEED
#define LIMIT_INTERVAL_MS CONFIG_LIMIT_INTERVAL
// ------ Private function prototypes -------------------------
static void motor_init(void);
static void motor_stop(void);
static void motor_open(void);
static void motor_close(void);
// ------ Private variables -----------------------------------
static xQueueHandle gpio_evt_queue = NULL;
/** @brief tag used for ESP serial console messages */
static const char TAG[] = "motor";
// ------ PUBLIC variable definitions -------------------------

//--------------------------------------------------------------
// FUNCTION DEFINITIONS
//--------------------------------------------------------------
/**
 * @brief Interrupt service routine for buttons and limit switches
*/
static void IRAM_ATTR gpio_isr(void* arg)
{
  uint32_t gpio_num = (uint32_t) arg;
  xQueueSendFromISR(gpio_evt_queue, &gpio_num, NULL);
}
/**
 * @brief Interrupt task for buttons and limit switches
*/
static void motor_isr_task(void* arg)
{
    uint32_t io_num;
    for(;;)
    {
        if(xQueueReceive(gpio_evt_queue, &io_num, portMAX_DELAY))
        {
            //ESP_LOGW(TAG, "GPIO[%d] intr, val: %d\n", io_num, gpio_get_level(io_num));
            if ((io_num==OPEN_LIMIT_PIN)&&(!gpio_get_level(OPEN_LIMIT_PIN)))
            {
              STOP_FLAG = true;
              GATE_STATE = OPENED;
              ESP_LOGW(TAG, "OPEN LIMIT isr!\n");
            }
            if ((io_num==CLOSE_LIMIT_PIN)&&(!gpio_get_level(CLOSE_LIMIT_PIN)))
            {
              STOP_FLAG = true;
              GATE_STATE = CLOSED;
              ESP_LOGW(TAG, "CLOSE LIMIT isr!\n");
            }
            if (((io_num==STOP_DOOR_PIN)&&(!gpio_get_level(STOP_DOOR_PIN)))||
                ((io_num==STOP_RF_PIN)&&(gpio_get_level(STOP_RF_PIN))))
            {
              STOP_FLAG = true;
              if (!((GATE_STATE==OPENED)|(GATE_STATE==CLOSED)))
              {GATE_STATE = STOPPED;}
              ESP_LOGW(TAG, "STOP isr!\n");
            }
            if (((io_num==OPEN_DOOR_PIN)&&(!gpio_get_level(OPEN_DOOR_PIN)))||
                ((io_num==OPEN_RF_PIN)&&(gpio_get_level(OPEN_RF_PIN))))
            {
              if (GATE_STATE == CLOSING) {
                    STOP_FLAG = true;
                    GATE_STATE = STOPPED;
                }
              DELAY_MS(800);
              GATE_STATE = OPENING;
              ESP_LOGW(TAG, "OPEN isr!\n");
            }
            if (((io_num==CLOSE_DOOR_PIN)&&(!gpio_get_level(CLOSE_DOOR_PIN)))||
                ((io_num==CLOSE_RF_PIN)&&(gpio_get_level(CLOSE_RF_PIN))))
            {
              if (GATE_STATE == OPENING) {
                    STOP_FLAG = true;
                    GATE_STATE = STOPPED;
                }
              DELAY_MS(800);
              GATE_STATE = CLOSING;
              ESP_LOGW(TAG, "CLOSE isr!\n");
            }
            DELAY_MS(10);
        }
    }
}

/**
 * @brief Configure MCPWM module for brushed dc motor and isr for buttons and limit switches
*/
static void motor_init(void)
{
    ESP_LOGI(TAG, "initializing gpio...\n");
    gpio_config_t io_conf;
    //disable interrupt
    io_conf.intr_type = GPIO_PIN_INTR_DISABLE;
    //set as output mode
    io_conf.mode = GPIO_MODE_INPUT_OUTPUT;
    //bit mask of the pins that you want to set
    io_conf.pin_bit_mask = MOTOR_PIN_SEL;
    //disable pull-down mode
    io_conf.pull_down_en = 0;
    //disable pull-up mode
    io_conf.pull_up_en = 1;
    //configure GPIO with the given settings
    gpio_config(&io_conf);

    //set initial values for gpio
    gpio_set_level(EN_PIN, LOW);
    gpio_set_level(INA_PIN, LOW);
    gpio_set_level(INB_PIN, LOW);

    //1. mcpwm gpio initialization
    mcpwm_gpio_init(MCPWM_UNIT_0, MCPWM0A, PWM_PIN);
    //2. initial mcpwm configuration
    ESP_LOGI(TAG, "Configuring Initial Parameters of mcpwm...\n");
    mcpwm_config_t pwm_config;
    pwm_config.frequency = FREQ;  //frequency in Hz,
    pwm_config.cmpr_a = 0;         //duty cycle of PWMxA = 0
    pwm_config.counter_mode = MCPWM_UP_COUNTER;
    pwm_config.duty_mode = MCPWM_DUTY_MODE_0;
    mcpwm_init(MCPWM_UNIT_0, MCPWM_TIMER_0, &pwm_config);    //Configure PWM0A with above settings
    
    //set initial value for pwm
    mcpwm_set_signal_low(MCPWM_UNIT_0, MCPWM_TIMER_0, MCPWM_OPR_A);
    
    ESP_LOGI(TAG, "Motor ready.\n");

    // --- limit switches and physical buttons declaration
    //interrupt of falling edge
    io_conf.intr_type = GPIO_PIN_INTR_NEGEDGE;
    //set as input mode    
    io_conf.mode = GPIO_MODE_INPUT;
    //bit mask of the pins
    io_conf.pin_bit_mask = ISR_PIN_SEL;
    //enable pull-up mode
    io_conf.pull_up_en = 1;
    //configure GPIO with the given settings
    gpio_config(&io_conf);

    // --- RF buttons declaration
    //interrupt of rising edge - since the RF module using reversed logic
    io_conf.intr_type = GPIO_PIN_INTR_POSEDGE;
    //set as input mode    
    io_conf.mode = GPIO_MODE_INPUT;
    //bit mask of the pins
    io_conf.pin_bit_mask = RF_PIN_SEL;
    //enable pull-down mode
    io_conf.pull_down_en = 1;
    //disable pull-up mode
    io_conf.pull_up_en = 0;
    //configure GPIO with the given settings
    gpio_config(&io_conf);
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

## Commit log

2020-08-18 update web server with motor control, bugs
    [config.h, main.c, motor.c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]
2020-10-03 update pcb and bills and configuration
    [V2_SkyLight.SchDoc, extra_components.xlsx]
2020-10-06 update bills and fix typos
    [extra_components.xlsx]
2020-11-12 update mechanical parts and pcb, fix final report
    [Bolt.0002.ipt, Bolt1.0003.ipt, Bản chi tiết - Giá đỡ động cơ.0013.dwg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]
